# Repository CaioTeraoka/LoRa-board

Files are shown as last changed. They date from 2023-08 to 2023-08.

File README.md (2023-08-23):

# LoRa-board
This project is a development board that was made with the purpose of being used to create and test simples projects that contains LoRaWAN communication. Besides the LoRaWAN usage, this board also has CAN bus communication and a sensor of temperature and humidity to expand the board possibilities.

## Specifications:
**LoRa Frequency** - Only 915MHz <br>
**Power** - 5V using the USB Micro <br>
**Stackup:**
1. Signal + Components
2. Ground
3. Power
4. Ground + Components

## Main Components
- STM32F103 <br>
The STM32F103 is a series of microcontrollers developed by STMicroelectronics. It's part of the STM32 family of microcontrollers, which are based on the ARM Cortex-M processor architecture. 

- LX1276 <br>
The SX1276 is a widely known RF (Radio Frequency) transceiver module. It is a product from Semtech, a semiconductor company that specializes in wireless communication solutions. The SX1276 is part of the Semtech's LoRa (Long Range) technology family.

- SN65HVD230 <br>
The SN65HVD230 is a popular transceiver chip designed for use in Controller Area Network (CAN) bus communication systems. CAN is a widely used network protocol in automotive and industrial applications for communication between various electronic control units (ECUs) or devices. 

- AHT20 <br>
The AHT20 is a digital humidity and temperature sensor manufactured by ASAIR, a company specializing in environmental sensing solutions. The AHT20 sensor is designed to accurately measure both humidity and temperature in various applications.

## 3D Model
Captura de tela de 2023-08-23 08-26-19



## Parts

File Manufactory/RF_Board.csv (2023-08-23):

Designator | Comment | Footprint | LCSC Part Number | Qtd
Y2 | MC-306_32.7680K-A0:ROHS | MC-306_32.7680K-A0_ROHS:XTAL_MC-306_32.7680K-A0 | C2650464 | 1
Y1 | X49SD8MSD2SC | LIB_X49SD8MSD2SC:X49SD8MSD2SC | C21263 | 1
XTAL1 | NX2016SA-32M-EXS00A-CS06465 | NX2016SA-32M-EXS00A-CS06465:NX2016SA_NDK | C1986260 | 1
U5 | AHT20 | AHT20:PSON100P300X300X110-6N | C2757850 | 1
U4 | SN65HVD230D | SN65HVD230D:SOIC127P599X175-8N | C12084 | 1
U3 | AMS1117-3.3 | AMS1117-3.3:SOT229P700X180-4N | C5199435 | 1
U2 | SX1276 | SX1276:QFN65P600X600X100-29N | C80171 | 1
U1 | STM32F103C8T6 | STM32F103C8T6:QFP50P900X900X160-48N | C8734 | 1
SW1 | SW_Push | Button_Switch_SMD:SW_SPST_TL3342 | C2886894 | 1
R13 | 10k | Resistor_SMD:R_0402_1005Metric | C100196 | 1
R12 | 10k | Resistor_SMD:R_0402_1005Metric | C100196 | 1
R10 | 120 | Resistor_SMD:R_0402_1005Metric | C284306 | 1
R9 | 510 | Resistor_SMD:R_0402_1005Metric | C208903 | 1
R8 | 510 | Resistor_SMD:R_0402_1005Metric | C208903 | 1
R7 | 4.7k | Resistor_SMD:R_0402_1005Metric | C525524 | 1
R6 | 20 | Resistor_SMD:R_0402_1005Metric | C102873 | 1
R5 | 20 | Resistor_SMD:R_0402_1005Metric | C102873 | 1
R4 | 100k | Resistor_SMD:R_0402_1005Metric | C431822 | 1
R3 | 100k | Resistor_SMD:R_0402_1005Metric | C431822 | 1
R2 | 1M | Resistor_SMD:R_0402_1005Metric | C323689 | 1
R1 | 10k | Resistor_SMD:R_0402_1005Metric | C100196 | 1
L4 | 6.2nH | Inductor_SMD:L_0402_1005Metric | C5137258 | 1
L3 | 10nH | Inductor_SMD:L_0402_1005Metric | C280981 | 1
L2 | 6.8nH | Inductor_SMD:L_0402_1005Metric | C114783 | 1
L1 | 33nH | Inductor_SMD:L_0402_1005Metric | C2757905 | 1
J7 | Conn_01x11_Socket | Connector_PinHeader_2.54mm:PinHeader_1x11_P2.54mm_Vertical | C2902694 | 1
J6 | Conn_01x11_Socket | Connector_PinHeader_2.54mm:PinHeader_1x11_P2.54mm_Vertical | C2902694 | 1
J5 | Conn_01x02_Socket | Connector_PinHeader_2.54mm:PinHeader_1x02_P2.54mm_Vertical | C160332 | 1
J4 | Conn_02x03_Odd_Even | Connector_PinHeader_2.54mm:PinHeader_2x03_P2.54mm_Vertical | C390684 | 1
J3 | Conn_01x04_Socket | Connector_PinHeader_2.54mm:PinHeader_1x04_P2.54mm_Vertical | C390680 | 1
J2 | U.FL-R-SMT-1(10) | U.FL-R-SMT-1_10_:HRS_U.FL-R-SMT-1(10) | C88374 | 1
J1 | 10118192-0001LF | 10118192-0001LF:AMPHENOL_10118192-0001LF | C132564 | 1
D2 | LED | LED_SMD:LED_1206_3216Metric | C965822 | 1
D1 | LED | LED_SMD:LED_1206_3216Metric | C965822 | 1
C40 | 100nF | Capacitor_SMD:C_0402_1005Metric | C163180 | 1
C39 | 100nF | Capacitor_SMD:C_0402_1005Metric | C163180 | 1
C38 | 1.8pF | Capacitor_SMD:C_0402_1005Metric | C147346 | 1
C37 | 100nF | Capacitor_SMD:C_0402_1005Metric | C163180 | 1
C36 | 20pF | Capacitor_SMD:C_0402_1005Metric | C778217 | 1
C35 | 20pF | Capacitor_SMD:C_0402_1005Metric | C778217 | 1
C34 | 20pF | Capacitor_SMD:C_0402_1005Metric | C778217 | 1
C33 | 20pF | Capacitor_SMD:C_0402_1005Metric | C778217 | 1
C32 | 100nF | Capacitor_SMD:C_0402_1005Metric | C163180 | 1
C31 | 1uF | Capacitor_SMD:C_0402_1005Metric | C162154 | 1
C30 | 100nF | Capacitor_SMD:C_0402_1005Metric | C163180 | 1
C21 | 100nF | Capacitor_SMD:C_0402_1005Metric | C163180 | 1
C20 | 100nF | Capacitor_SMD:C_0402_1005Metric | C163180 | 1
C19 | 100nF | Capacitor_SMD:C_0402_1005Metric | C163180 | 1
C18 | 100nF | Capacitor_SMD:C_0402_1005Metric | C163180 | 1
C17 | 4.7pF | Capacitor_SMD:C_0402_1005Metric | C311706 | 1
C16 | 33pF | Capacitor_SMD:C_0402_1005Metric | C382724 | 1
C15 | 2.2pF | Capacitor_SMD:C_0402_1005Metric | C123473 | 1
C14 | 47pF | Capacitor_SMD:C_0402_1005Metric | C525215 | 1
C13 | 10nF | Capacitor_SMD:C_0402_1005Metric | C466608 | 1
C12 | 100nF | Capacitor_SMD:C_0402_1005Metric | C163180 | 1
C11 | 47pF | Capacitor_SMD:C_0402_1005Metric | C525215 | 1
C10 | 100nF | Capacitor_SMD:C_0402_1005Metric | C163180 | 1
C9 | 100nF | Capacitor_SMD:C_0402_1005Metric | C163180 | 1
C8 | 10uF | Capacitor_SMD:C_0402_1005Metric | C307416 | 1
C7 | 100nF | Capacitor_SMD:C_0402_1005Metric | C163180 | 1
C6 | 100nF | Capacitor_SMD:C_0402_1005Metric | C163180 | 1
C5 | 10uF | Capacitor_SMD:C_0402_1005Metric | C307416 | 1
C4 | 100nF | Capacitor_SMD:C_0402_1005Metric | C163180 | 1
C3 | 100nF | Capacitor_SMD:C_0402_1005Metric | C163180 | 1
C2 | 15pF | Capacitor_SMD:C_0402_1005Metric | C2880416 | 1
C1 | 15pF | Capacitor_SMD:C_0402_1005Metric | C2880416 | 1

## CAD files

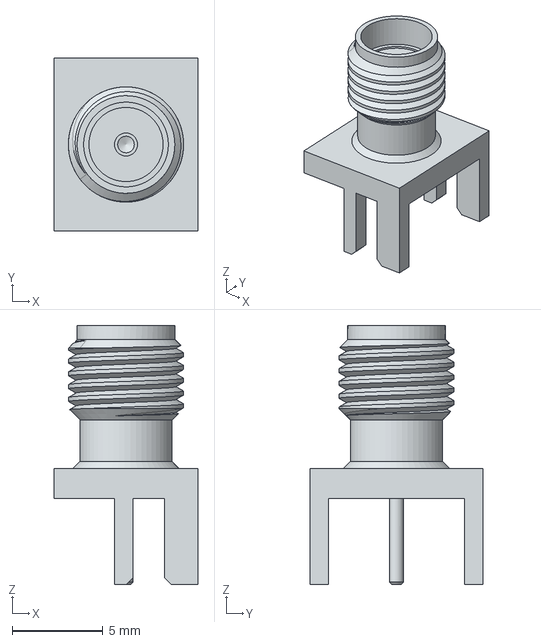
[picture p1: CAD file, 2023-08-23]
Footprints/142-0701-801/142-0701-801.step
7.92 x 9.53 x 14.3 mm

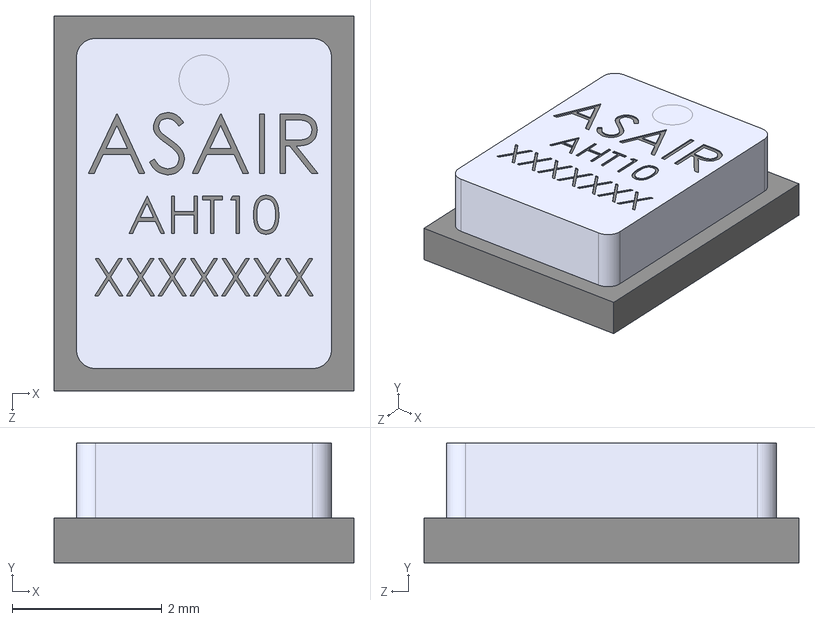
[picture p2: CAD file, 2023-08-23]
Footprints/AHT20/AHT10.stp
4.00 x 1.60 x 5.00 mm

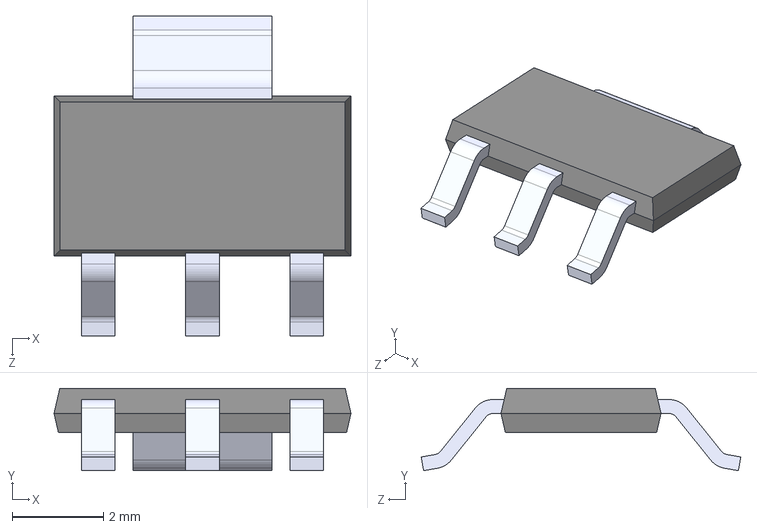
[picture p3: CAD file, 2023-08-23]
Footprints/AMS1117-3.3/AMS1117-3.3.step
6.50 x 1.80 x 7.00 mm

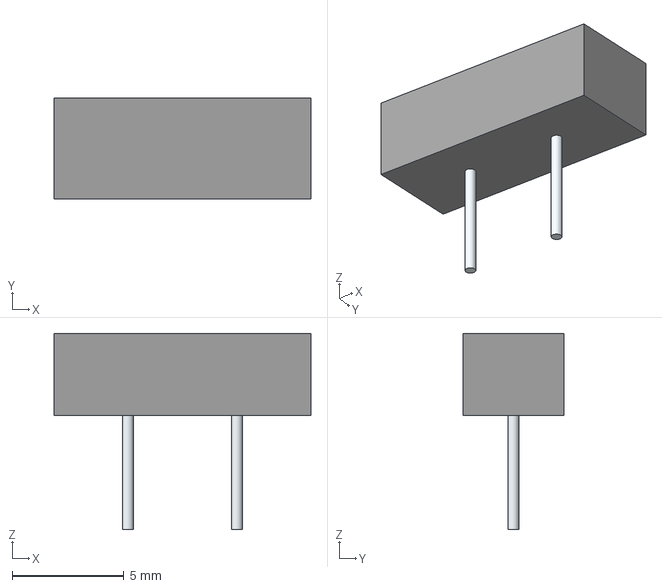
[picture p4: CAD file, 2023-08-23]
Footprints/LIB_X49SD8MSD2SC/X49SD8MSD2SC.stp
11.5 x 4.50 x 8.78 mm
Leads x 2

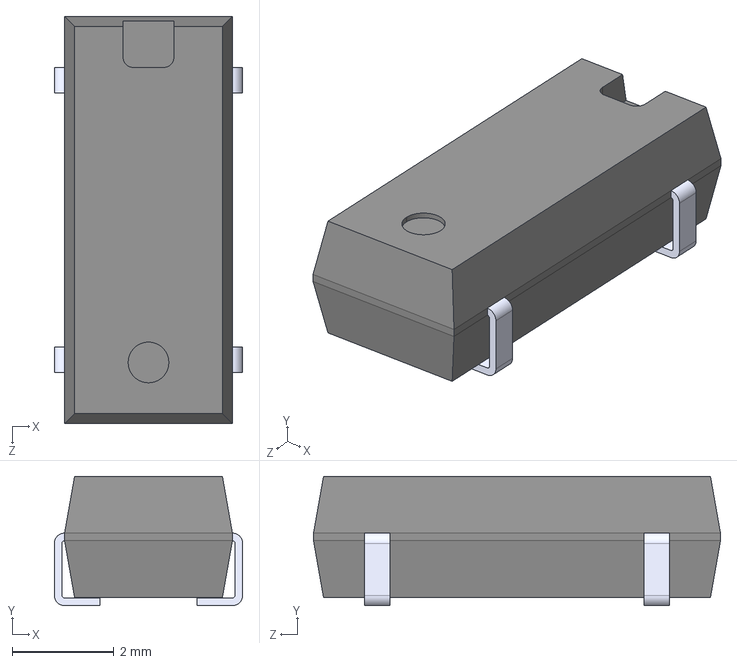
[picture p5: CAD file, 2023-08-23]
Footprints/MC-306_32.7680K-A0_ROHS/MC-306_32.7680K-A0_ROHS.step
3.70 x 2.54 x 8.00 mm

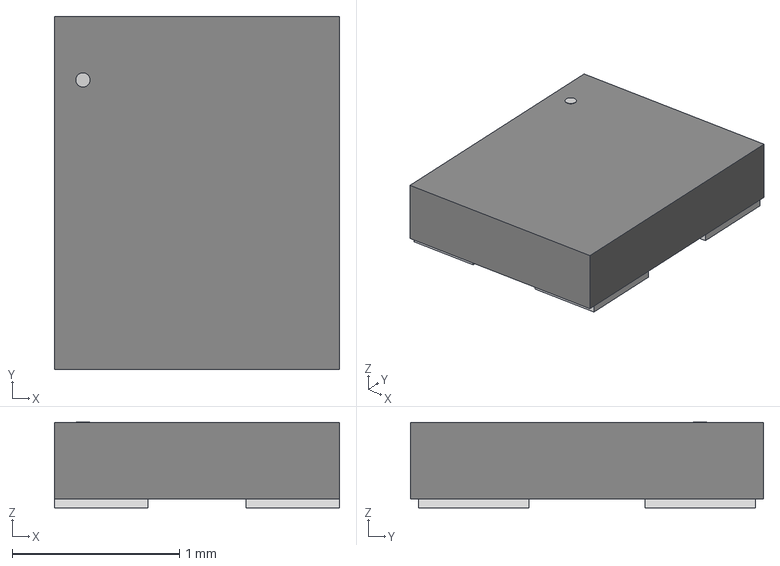
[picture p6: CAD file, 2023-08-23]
Footprints/NX2016SA-32M-EXS00A-CS06465/NX2016SA_NDK.step
1.70 x 2.11 x 0.511 mm

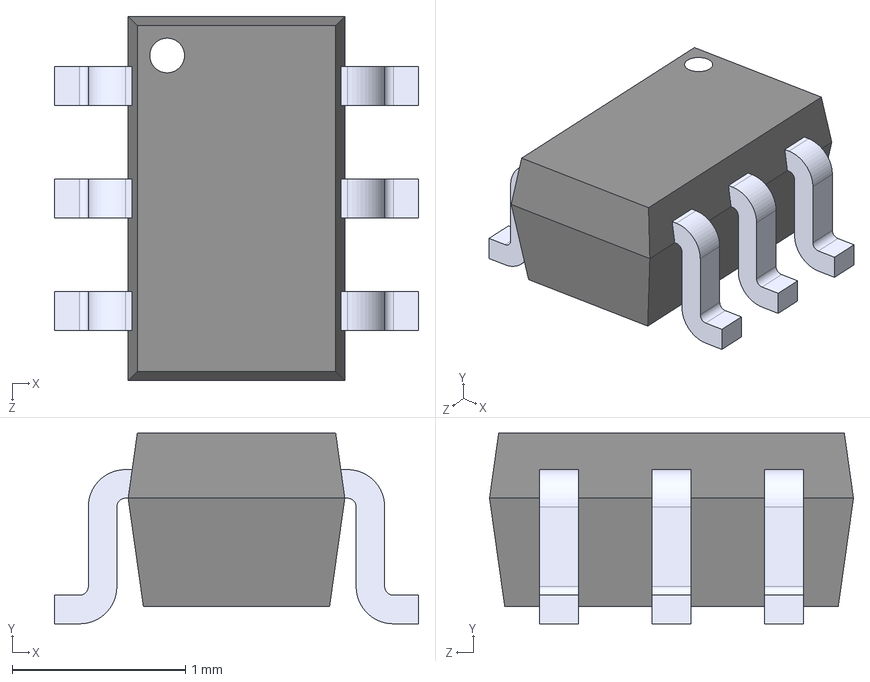
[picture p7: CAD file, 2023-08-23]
Footprints/PE4259/PE4259.step
2.10 x 1.10 x 2.10 mm

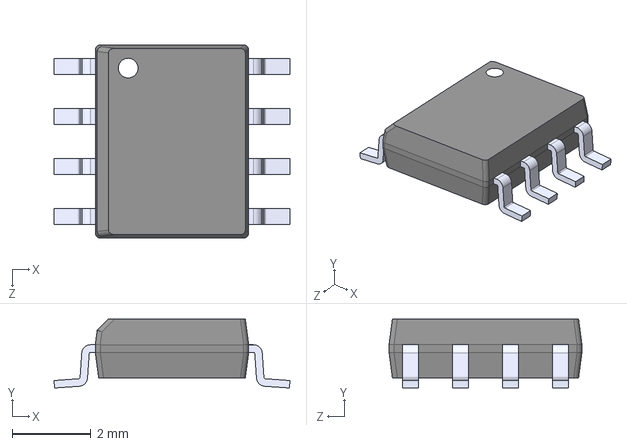
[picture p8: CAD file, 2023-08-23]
Footprints/SN65HVD230D/SN65HVD230D.step
5.99 x 1.75 x 4.90 mm

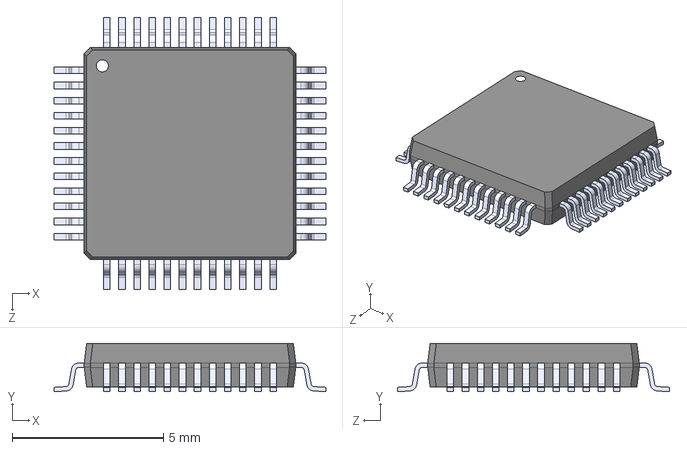
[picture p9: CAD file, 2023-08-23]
Footprints/STM32F103C8T6/STM32F103C8T6.step
9.00 x 1.60 x 9.00 mm

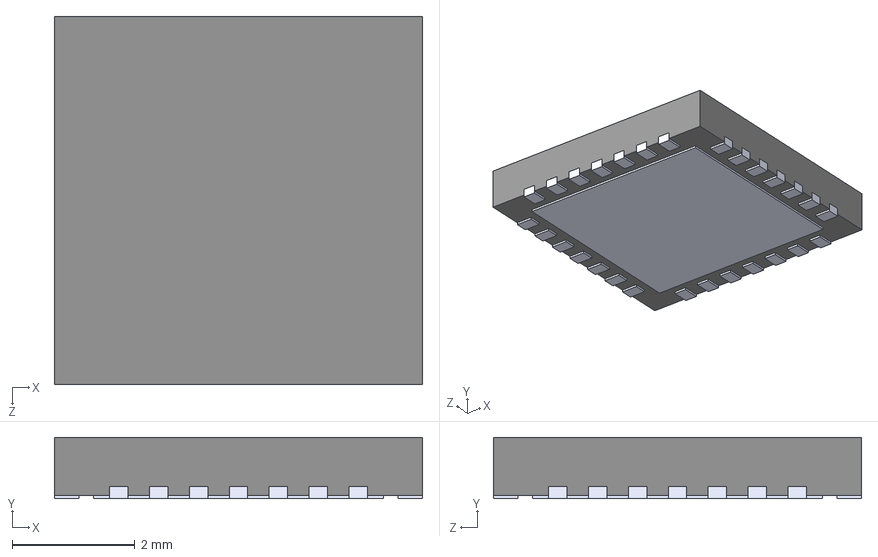
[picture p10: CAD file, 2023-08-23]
Footprints/SX1276/SX1276.step
6.00 x 1 x 6.00 mm

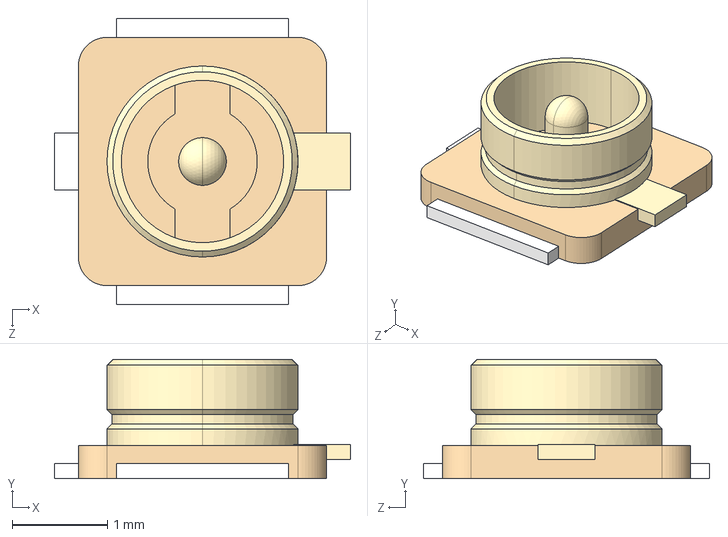
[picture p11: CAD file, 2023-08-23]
Footprints/U.FL-R-SMT-1_10_/U.FL-R-SMT-1_10_.step
3.10 x 1.25 x 3.00 mm

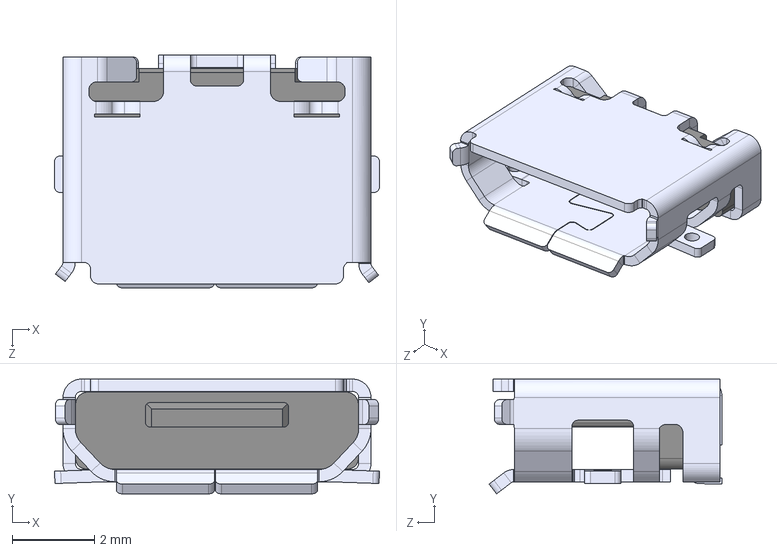
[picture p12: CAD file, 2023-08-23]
Footprints/10118192-0001LF/10118192-0001LF.step
7.91 x 2.79 x 5.67 mm

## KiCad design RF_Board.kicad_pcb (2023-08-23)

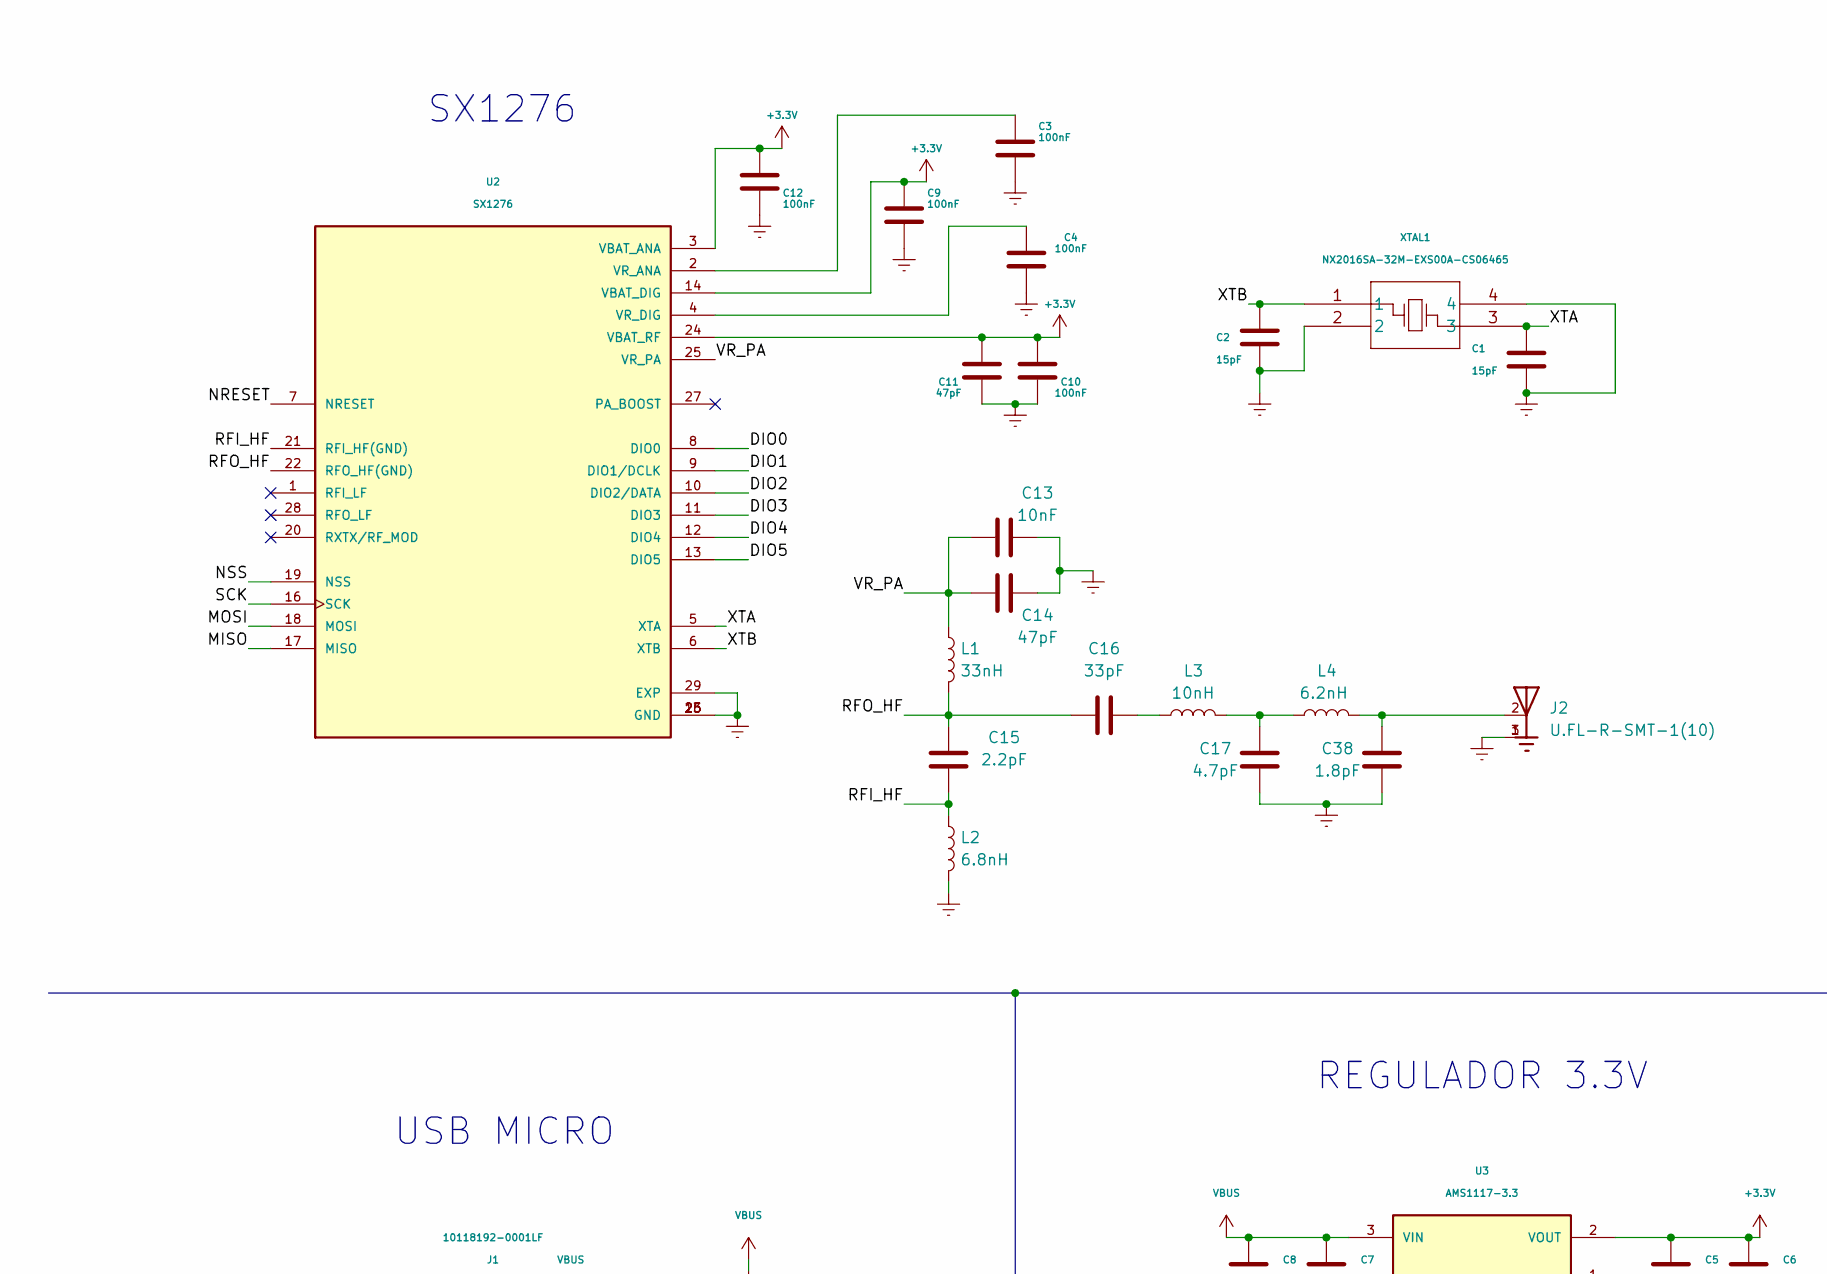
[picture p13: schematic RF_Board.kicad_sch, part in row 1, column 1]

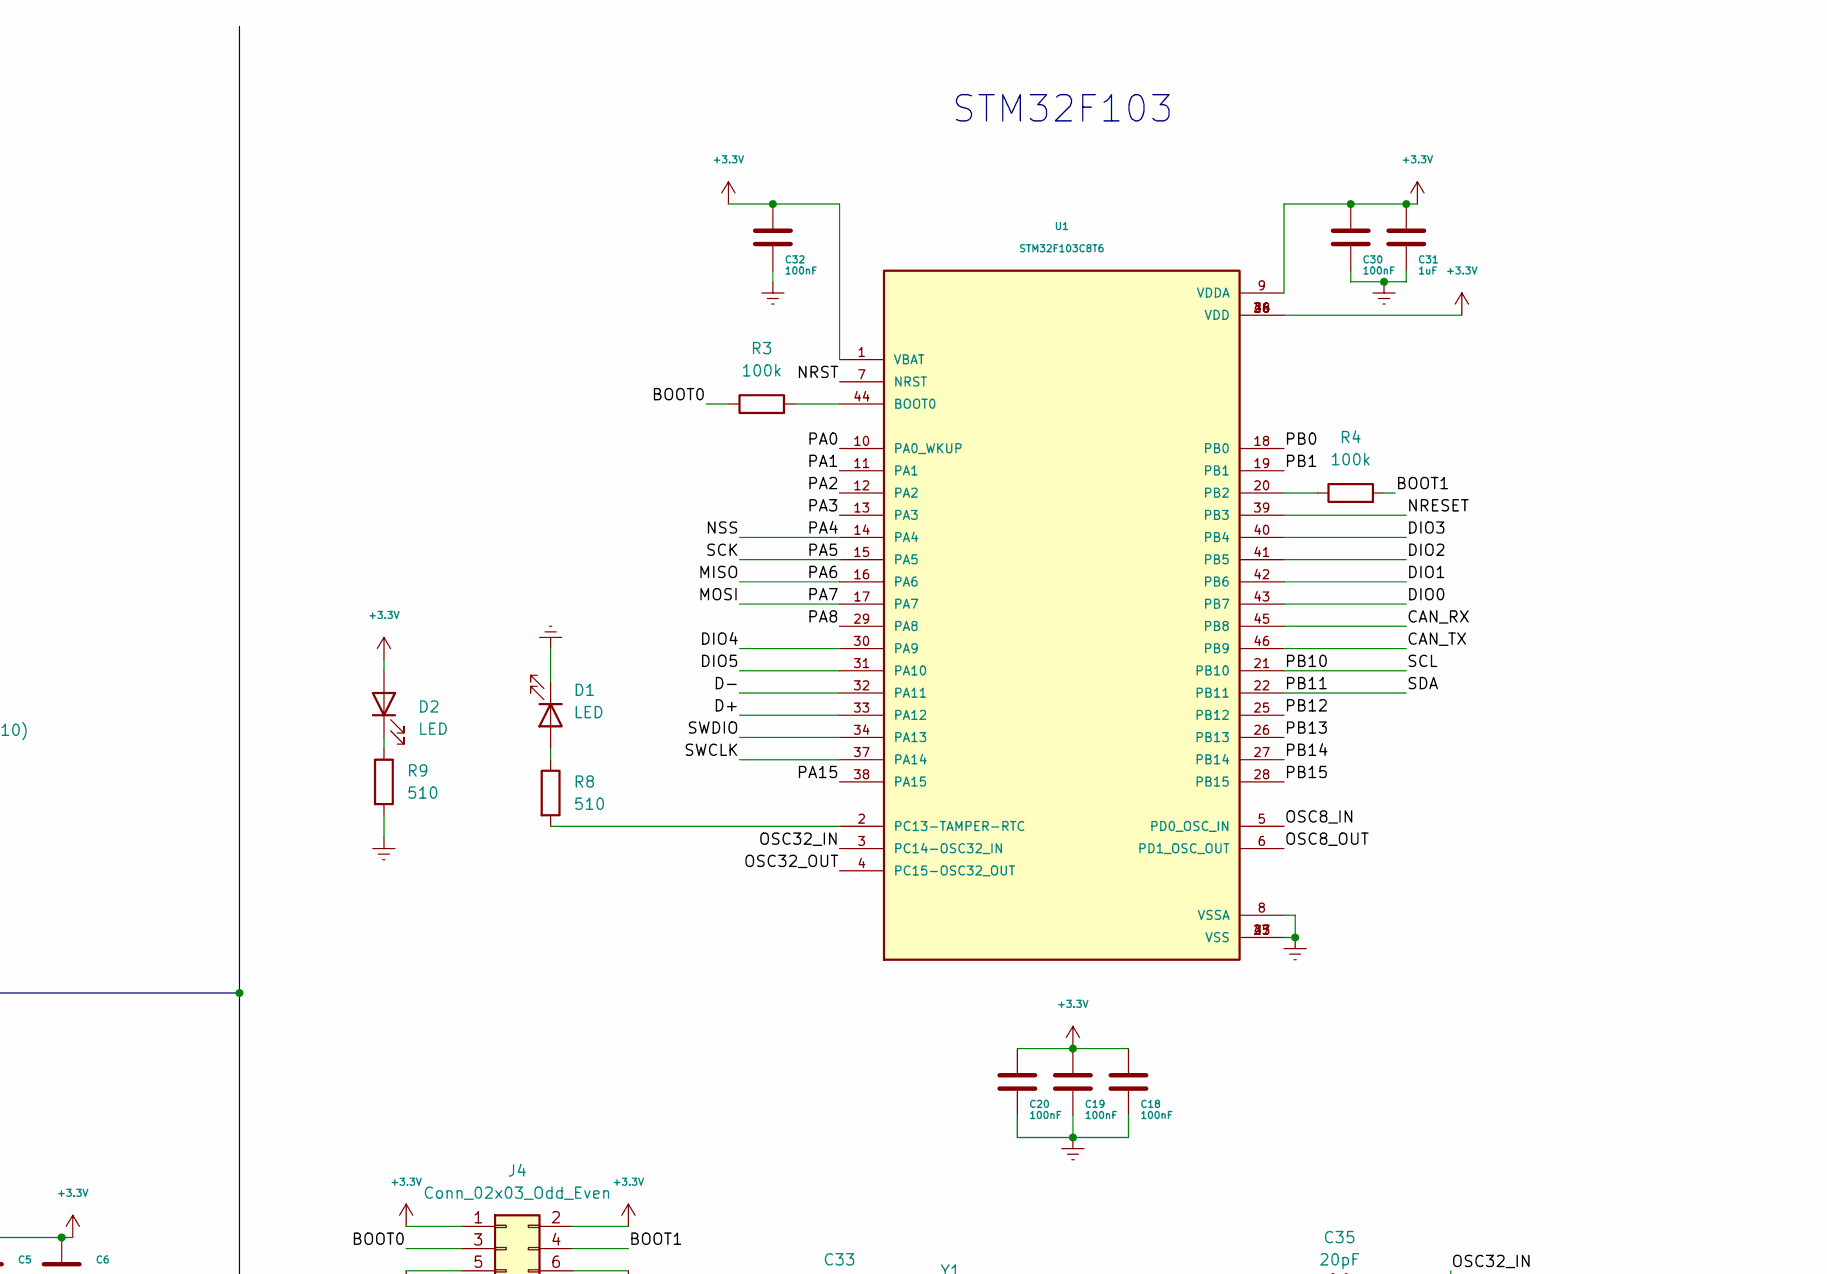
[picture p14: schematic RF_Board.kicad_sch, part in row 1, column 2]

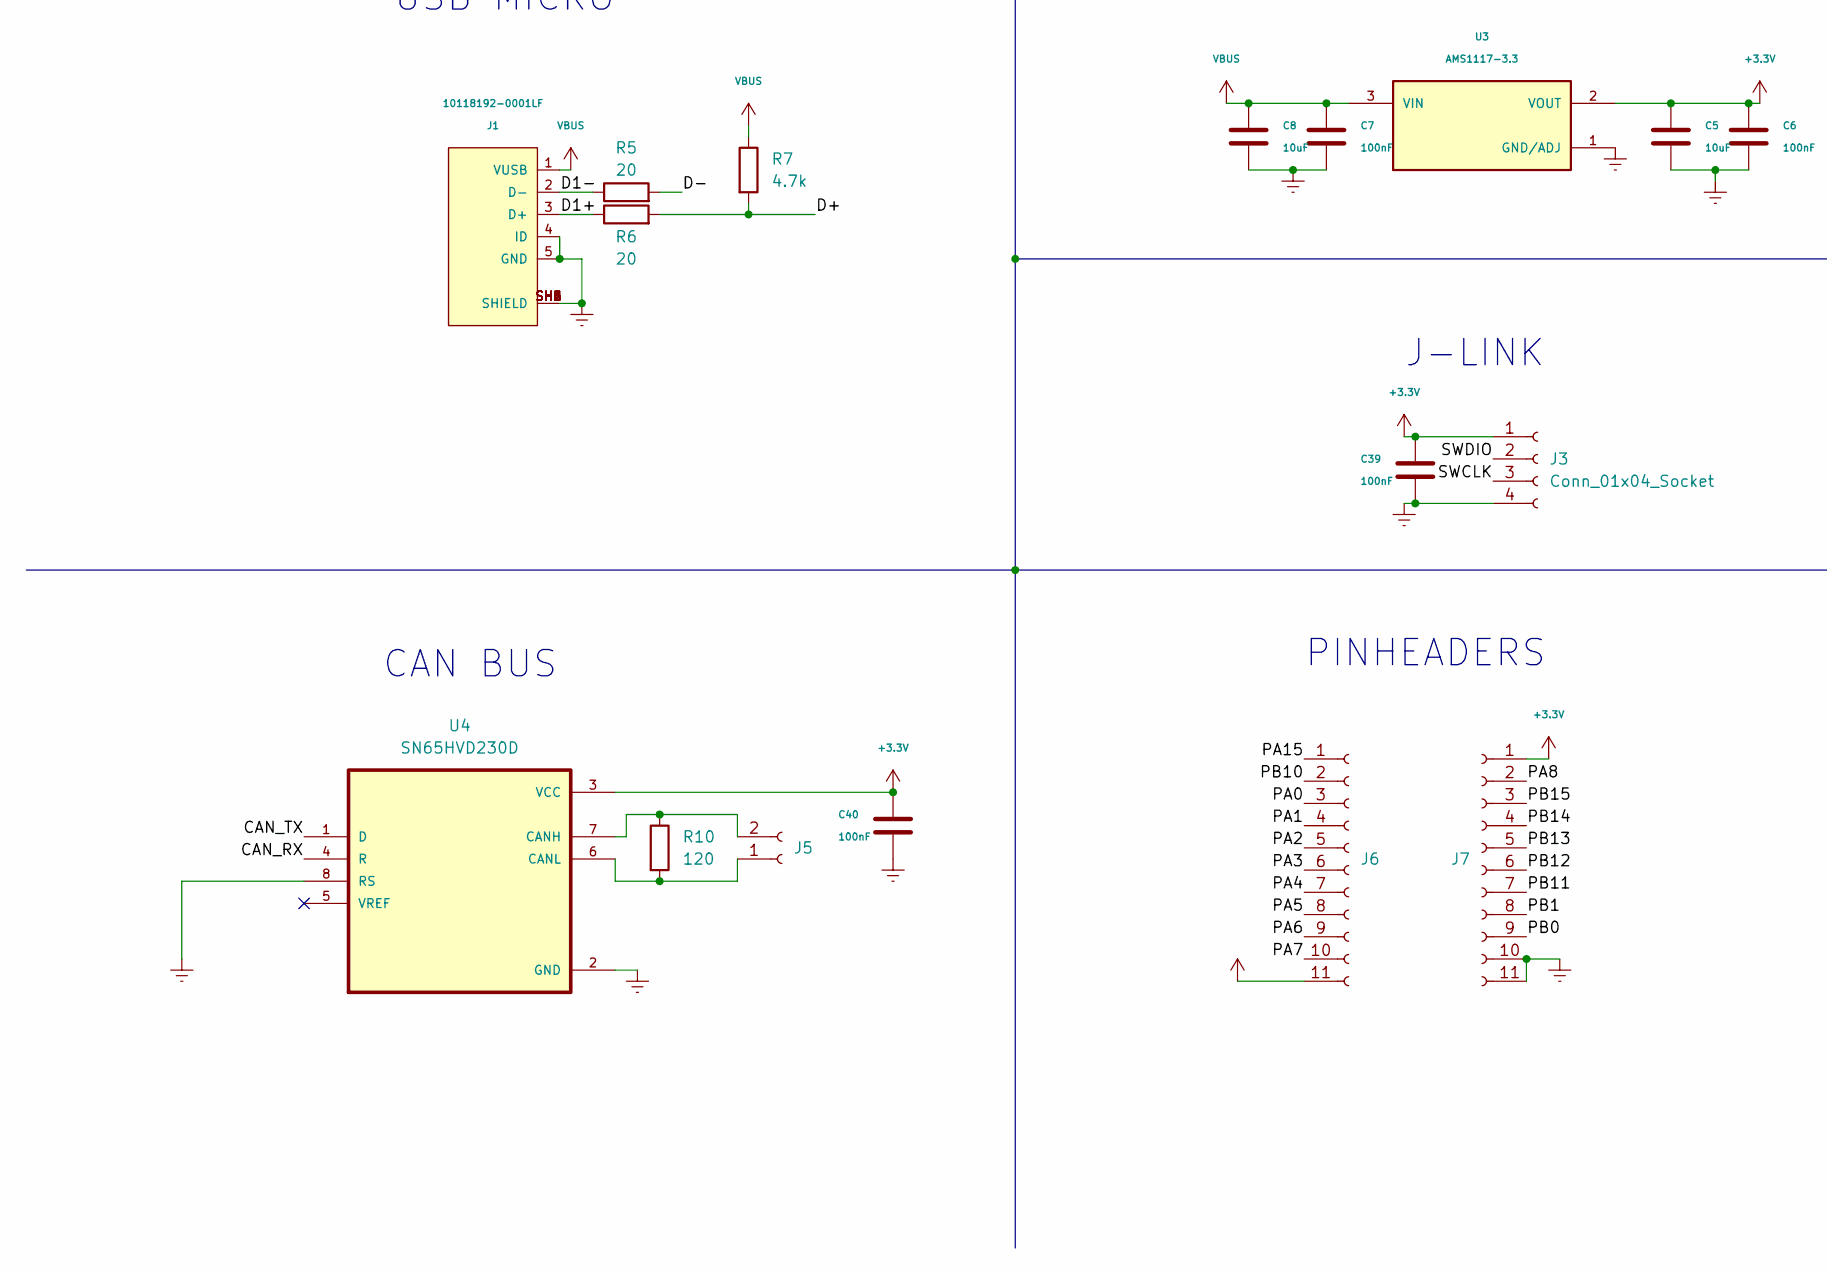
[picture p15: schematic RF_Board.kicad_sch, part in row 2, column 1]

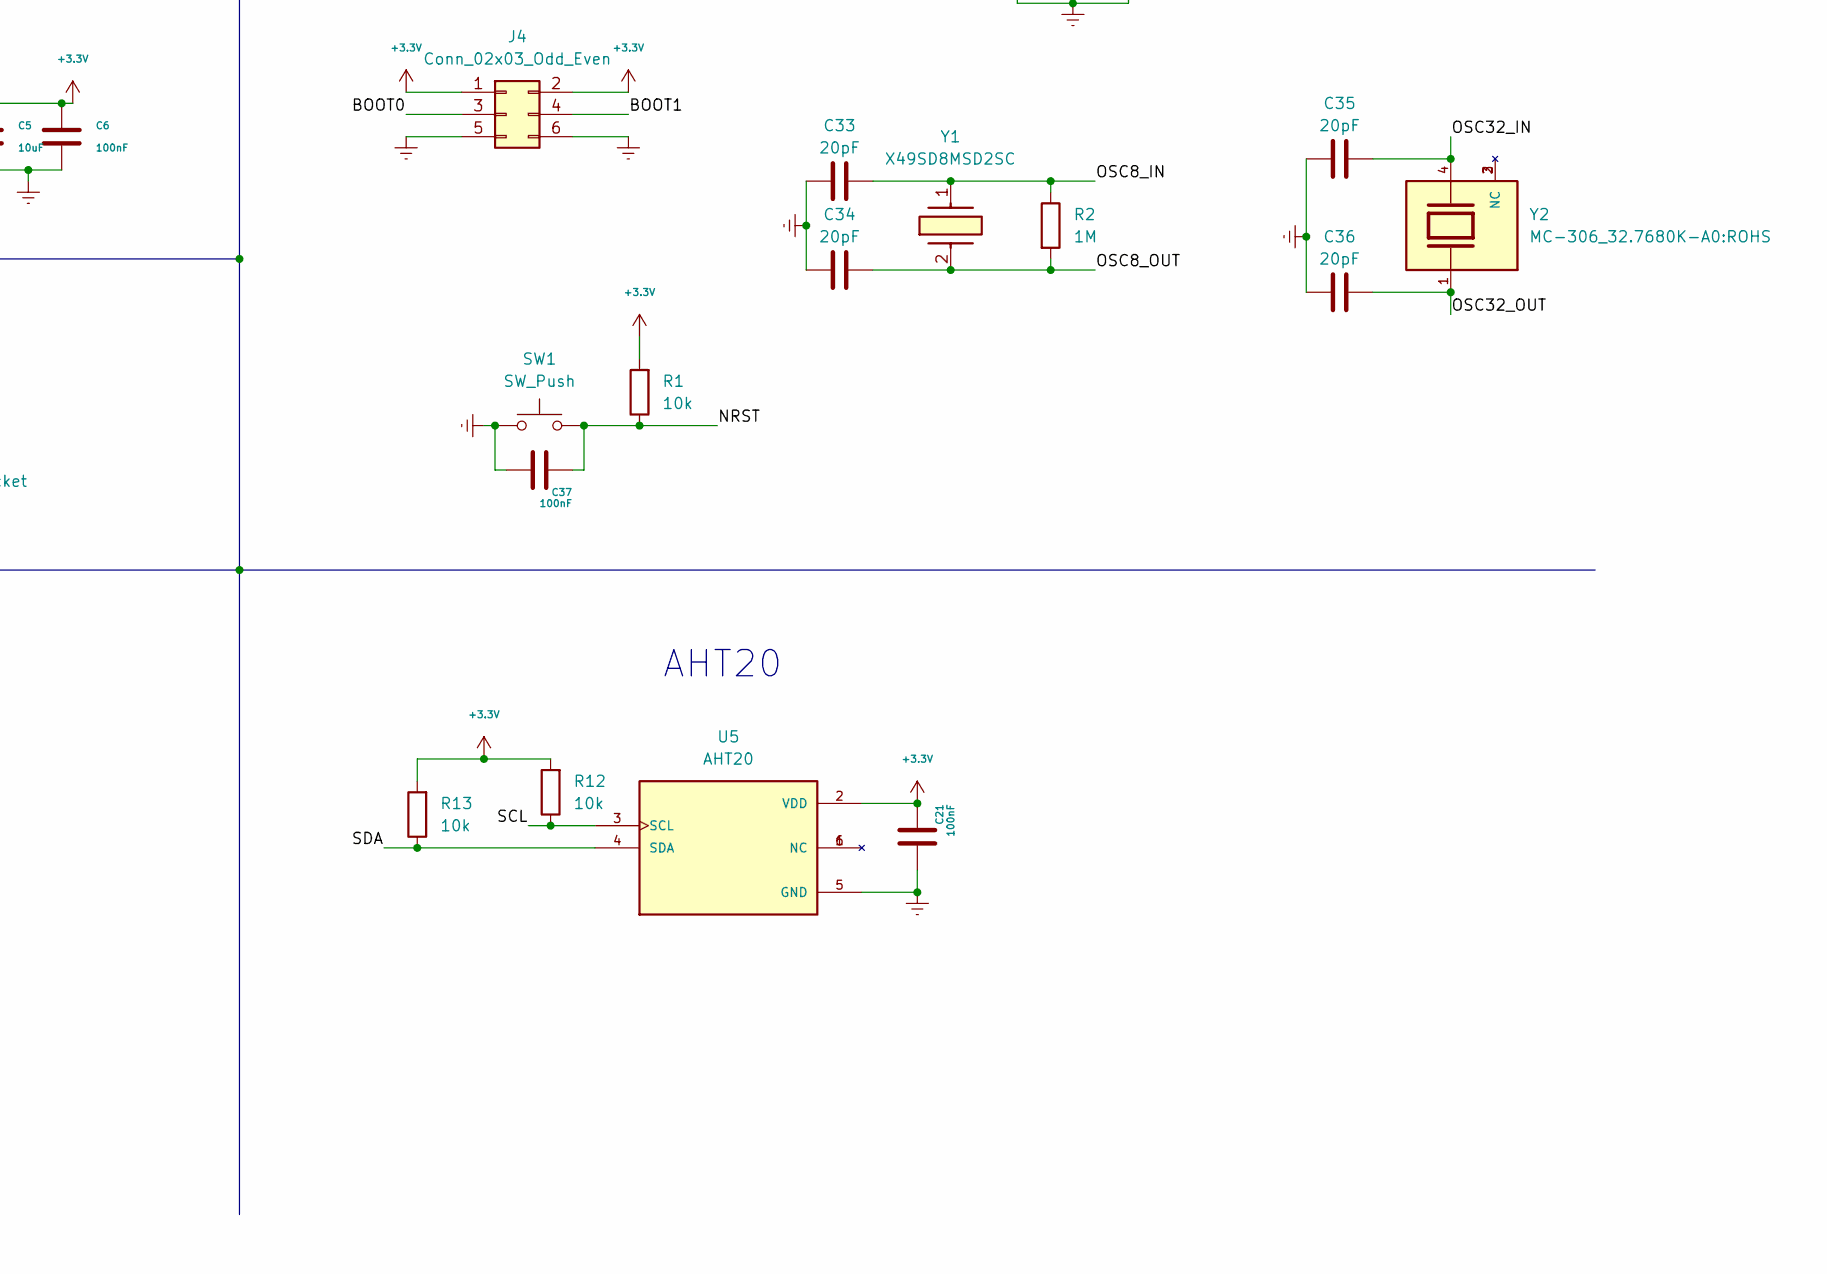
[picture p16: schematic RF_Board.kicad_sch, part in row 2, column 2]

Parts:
C1, C2: 15pF; C_0402_1005Metric; LCSC PART NUMBER C2880416
C3, C4, C6, C7, C9, C10, C12, C18, C19, C20, C21, C30, C32, C37, C39, C40: 100nF; C_0402_1005Metric; LCSC PART NUMBER C163180
C5, C8: 10uF; C_0402_1005Metric; LCSC PART NUMBER C307416
C11, C14: 47pF; C_0402_1005Metric; LCSC PART NUMBER C525215
C13: 10nF; C_0402_1005Metric; LCSC PART NUMBER C466608
C15: 2.2pF; C_0402_1005Metric; LCSC PART NUMBER C123473
C16: 33pF; C_0402_1005Metric; LCSC PART NUMBER C382724
C17: 4.7pF; C_0402_1005Metric; LCSC PART NUMBER C311706
C31: 1uF; C_0402_1005Metric; LCSC PART NUMBER C162154
C33, C34, C35, C36: 20pF; C_0402_1005Metric; LCSC PART NUMBER C778217
C38: 1.8pF; C_0402_1005Metric; LCSC PART NUMBER C147346
D1, D2: LED; LED_1206_3216Metric; LCSC PART NUMBER C965822
J1: 10118192-0001LF; AMPHENOL_10118192-0001LF; PARTREV B; LCSC PART NUMBER C132564
J2: U.FL-R-SMT-1(10); HRS_U.FL-R-SMT-1(10); LCSC PART NUMBER C88374
J3: Conn_01x04_Socket; PinHeader_1x04_P2.54mm_Vertical; LCSC PART NUMBER C390680
J4: Conn_02x03_Odd_Even; PinHeader_2x03_P2.54mm_Vertical; LCSC PART NUMBER C390684
J5: Conn_01x02_Socket; PinHeader_1x02_P2.54mm_Vertical; LCSC PART NUMBER C160332
J6, J7: Conn_01x11_Socket; PinHeader_1x11_P2.54mm_Vertical; LCSC PART NUMBER C2902694
L1: 33nH; L_0402_1005Metric; LCSC PART NUMBER C2757905
L2: 6.8nH; L_0402_1005Metric; LCSC PART NUMBER C114783
L3: 10nH; L_0402_1005Metric; LCSC PART NUMBER C280981
L4: 6.2nH; L_0402_1005Metric; LCSC PART NUMBER C5137258
R1, R12, R13: 10k; R_0402_1005Metric; LCSC PART NUMBER C100196
R2: 1M; R_0402_1005Metric; LCSC PART NUMBER C323689
R3, R4: 100k; R_0402_1005Metric; LCSC PART NUMBER C431822
R5, R6: 20; R_0402_1005Metric; LCSC PART NUMBER C102873
R7: 4.7k; R_0402_1005Metric; LCSC PART NUMBER C525524
R8, R9: 510; R_0402_1005Metric; LCSC PART NUMBER C208903
R10: 120; R_0402_1005Metric; LCSC PART NUMBER C284306
SW1: SW_Push; SW_SPST_TL3342; LCSC PART NUMBER C2886894
U1: STM32F103C8T6; QFP50P900X900X160-48N; PARTREV 10; LCSC PART NUMBER C8734
U2: SX1276; QFN65P600X600X100-29N; PARTREV 6; LCSC PART NUMBER C80171
U3: AMS1117-3.3; SOT229P700X180-4N; PARTREV N/A; LCSC PART NUMBER C5199435
U4: SN65HVD230D; SOIC127P599X175-8N; LCSC PART NUMBER C12084
U5: AHT20; PSON100P300X300X110-6N; PARTREV V1.0; LCSC PART NUMBER C2757850
XTAL1: NX2016SA-32M-EXS00A-CS06465; NX2016SA_NDK; LCSC PART NUMBER C1986260
Y1: X49SD8MSD2SC; Manufacturer_Part_Number X49SD8MSD2SC; LCSC PART NUMBER C21263
Y2: MC-306_32.7680K-A0:ROHS; XTAL_MC-306_32.7680K-A0; PARTREV N/A; LCSC PART NUMBER C2650464

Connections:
+3.3V: C5.1, C6.1, C9.2, C10.2, C11.2, C12.2, C18.1, C19.1, C20.1, C21.2, C30.1, C31.1, C32.1, C39.1, C40.1, D2.2 (A), J3.1, J4.1, J4.2, J7.1, R1.2, R12.2, R13.2, U1.1 (VBAT), U1.9 (VDDA), U1.24 (VDD), U1.36 (VDD), U1.48 (VDD), U2.3 (VBAT_ANA), U2.14 (VBAT_DIG), U2.24 (VBAT_RF), U3.2 (VOUT), U4.3 (VCC), U5.2 (VDD)
/BOOT0: J4.3, R3.1
/BOOT1: J4.4, R4.2
/CAN_RX: U1.45 (PB8), U4.4 (R)
/CAN_TX: U1.46 (PB9), U4.1 (D)
/D1+: J1.3 (D+), R6.1
/D1-: J1.2 (D-), R5.1
/D+: R6.2, R7.2, U1.33 (PA12)
/D-: R5.2, U1.32 (PA11)
/DIO0: U1.43 (PB7), U2.8 (DIO0)
/DIO1: U1.42 (PB6), U2.9 (DIO1/DCLK)
/DIO2: U1.41 (PB5), U2.10 (DIO2/DATA)
/DIO3: U1.40 (PB4), U2.11 (DIO3)
/DIO4: U1.30 (PA9), U2.12 (DIO4)
/DIO5: U1.31 (PA10), U2.13 (DIO5)
/MISO: J6.9, U1.16 (PA6), U2.17 (MISO)
/MOSI: J6.10, U1.17 (PA7), U2.18 (MOSI)
/NRESET: U1.39 (PB3), U2.7 (NRESET)
/NRST: C37.2, R1.1, SW1.2, U1.7 (NRST)
/NSS: J6.7, U1.14 (PA4), U2.19 (NSS)
/OSC8_IN: C33.2, R2.1, U1.5 (PD0_OSC_IN), Y1.1
/OSC8_OUT: C34.2, R2.2, U1.6 (PD1_OSC_OUT), Y1.2 (CRYSTAL__2)
/OSC32_IN: C35.2, U1.3 (PC14-OSC32_IN), Y2.4
/OSC32_OUT: C36.2, U1.4 (PC15-OSC32_OUT), Y2.1
/PA0: J6.3, U1.10 (PA0_WKUP)
/PA1: J6.4, U1.11 (PA1)
/PA2: J6.5, U1.12 (PA2)
/PA3: J6.6, U1.13 (PA3)
/PA5: J6.8, U1.15 (PA5), U2.16 (SCK)
/PA8: J7.2, U1.29 (PA8)
/PA15: J6.1, U1.38 (PA15)
/PB0: J7.9, U1.18 (PB0)
/PB1: J7.8, U1.19 (PB1)
/PB10: J6.2, R12.1, U1.21 (PB10), U5.3 (SCL)
/PB11: J7.7, R13.1, U1.22 (PB11), U5.4 (SDA)
/PB12: J7.6, U1.25 (PB12)
/PB13: J7.5, U1.26 (PB13)
/PB14: J7.4, U1.27 (PB14)
/PB15: J7.3, U1.28 (PB15)
/RFI_HF: C15.1, L2.1, U2.21 (RFI_HF(GND))
/RFO_HF: C15.2, C16.2, L1.2, U2.22 (RFO_HF(GND))
/SWCLK: J3.3, U1.37 (PA14)
/SWDIO: J3.2, U1.34 (PA13)
/VR_PA: C13.1, C14.1, L1.1, U2.25 (VR_PA)
/XTA: C1.1, U2.5 (XTA), XTAL1.3
/XTB: C2.1, U2.6 (XTB), XTAL1.1
Earth: C1.2, C2.2, C3.1, C4.1, C5.2, C6.2, C7.2, C8.2, C9.1, C10.1, C11.1, C12.1, C13.2, C14.2, C17.2, C18.2, C19.2, C20.2, C21.1, C30.2, C31.2, C32.2, C33.1, C34.1, C35.1, C36.1, C37.1, C38.2, C39.2, C40.2, D1.1 (K), J1.4 (ID), J1.5 (GND), J1.SH1 (SHIELD), J1.SH2 (SHIELD), J1.SH3 (SHIELD), J1.SH4 (SHIELD), J1.SH5 (SHIELD), J1.SH6 (SHIELD), J2.1, J2.3, J3.4, J4.5, J4.6, J7.10, J7.11, L2.2, R9.2, SW1.1, U1.8 (VSSA), U1.23 (VSS), U1.35 (VSS), U1.47 (VSS), U2.15 (GND), U2.23 (GND), U2.26 (GND), U2.29 (EXP), U3.1 (GND/ADJ), U4.2 (GND), U4.8 (RS), U5.5 (GND), XTAL1.2, XTAL1.4
unnamed: C16.1, L3.1
unnamed: C17.1, L3.2, L4.1
unnamed: C38.1, J2.2, L4.2
unnamed: D1.2 (A), R8.1
unnamed: D2.1 (K), R9.1
unnamed: J5.1, R10.2, U4.6 (CANL)
unnamed: J5.2, R10.1, U4.7 (CANH)
unnamed: R3.2, U1.44 (BOOT0)
unnamed: R4.1, U1.20 (PB2)
unnamed: R8.2, U1.2 (PC13-TAMPER-RTC)
unnamed: C3.2, U2.2 (VR_ANA)
unnamed: C4.2, U2.4 (VR_DIG)
VBUS: C7.1, C8.1, J1.1 (VUSB), J6.11, R7.1, U3.3 (VIN)

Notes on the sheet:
USB MICRO
CAN BUS
PINHEADERS
J-LINK
SX1276
REGULADOR 3.3V
AHT20
STM32F103

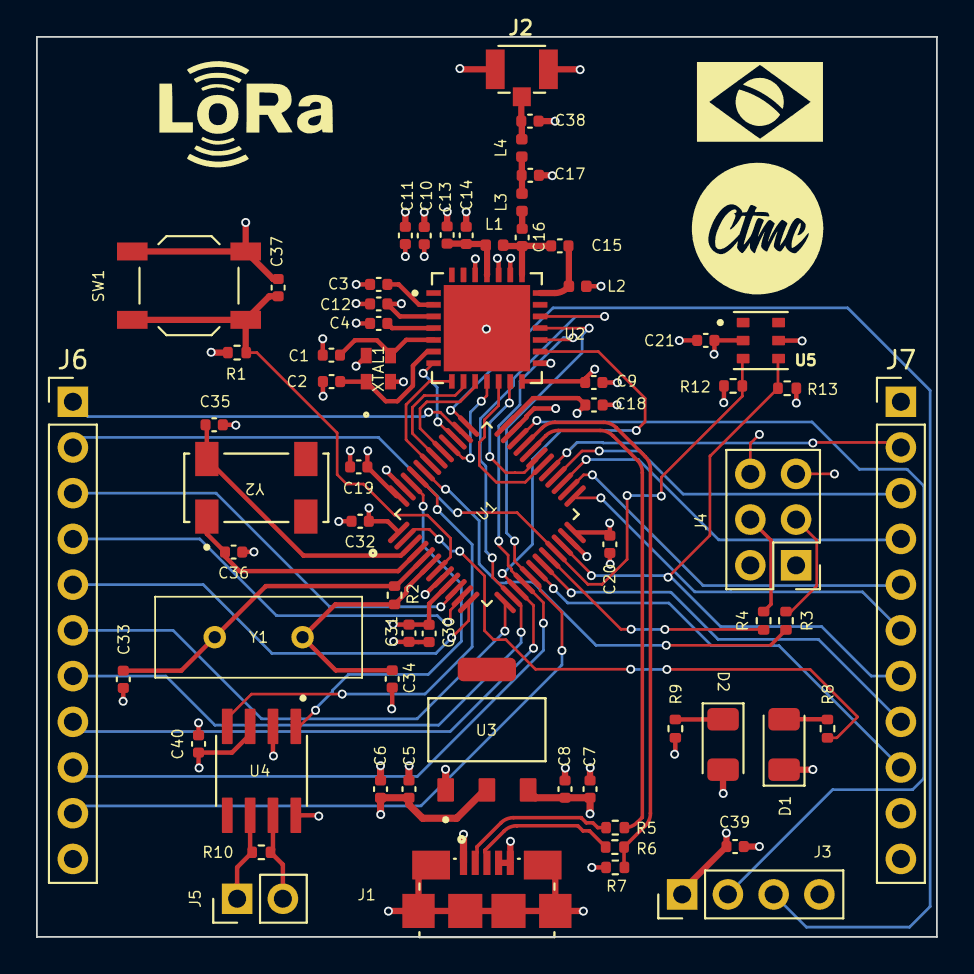
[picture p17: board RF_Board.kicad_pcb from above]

Board: 4 copper layers, 50.0 x 50.0 mm, 66 parts (0 on the bottom side), 60 nets.
